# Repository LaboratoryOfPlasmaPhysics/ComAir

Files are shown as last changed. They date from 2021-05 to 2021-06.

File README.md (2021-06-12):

# ComAir

A LoRa air quality sensor powered with an indoor solar pannel.

This PCB uses:
- as MCU: [STM32L412C8](https://www.st.com/en/microcontrollers-microprocessors/stm32l412c8.html)
- for LoRa communication: [RFM95](https://www.hoperf.com/modules/lora/RFM95.html)
- for energy harvesting: [SPV1050](https://www.st.com/en/power-management/spv1050.html)
- any 18650 lithium cell (could be recycled from old laptop battery)
- as solar pannel, one or two: [LL200-4.8-37](https://www.powerfilmsolar.com/products/electronic-component-solar-panels/indoor-light-series/ll200-48-37) 
- for CO2 sensing: [SCD41](https://www.sensirion.com/en/environmental-sensors/carbon-dioxide-sensors/carbon-dioxide-sensor-scd4x/)
- for temperature and humidity: either [SCD41](https://www.sensirion.com/en/environmental-sensors/carbon-dioxide-sensors/carbon-dioxide-sensor-scd4x/) or [SHTC3](https://www.sensirion.com/en/environmental-sensors/humidity-sensors/digital-humidity-sensor-shtc3-our-new-standard-for-consumer-electronics/)

**Warning** this project is still work in progress, PCB may still contain errors.

PCB V1.0 preview:
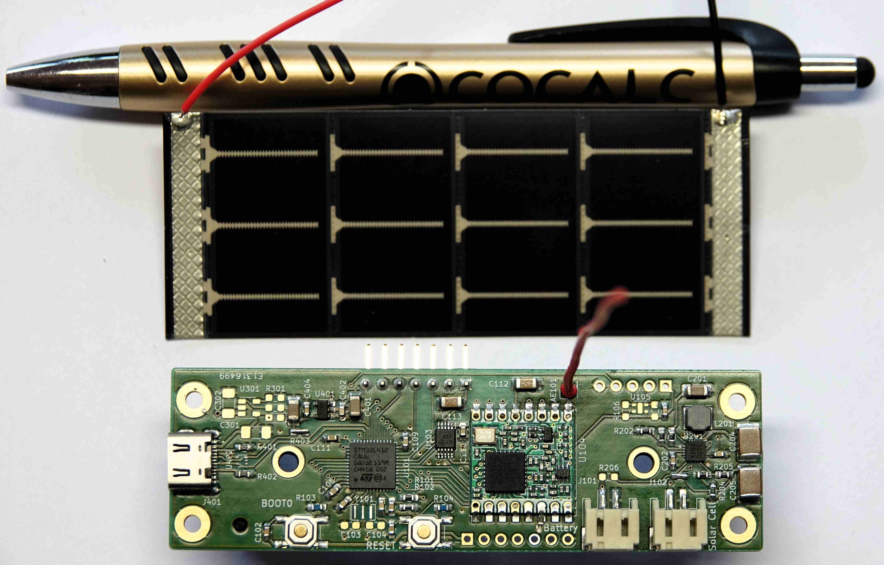
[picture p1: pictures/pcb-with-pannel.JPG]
PCB with solar pannel


## TODO

- [ ] Write some basic testing firmware
- [ ] Evaluate energy balance 
- [ ] Optimize energy usage

## License 
- CC-BY-SA

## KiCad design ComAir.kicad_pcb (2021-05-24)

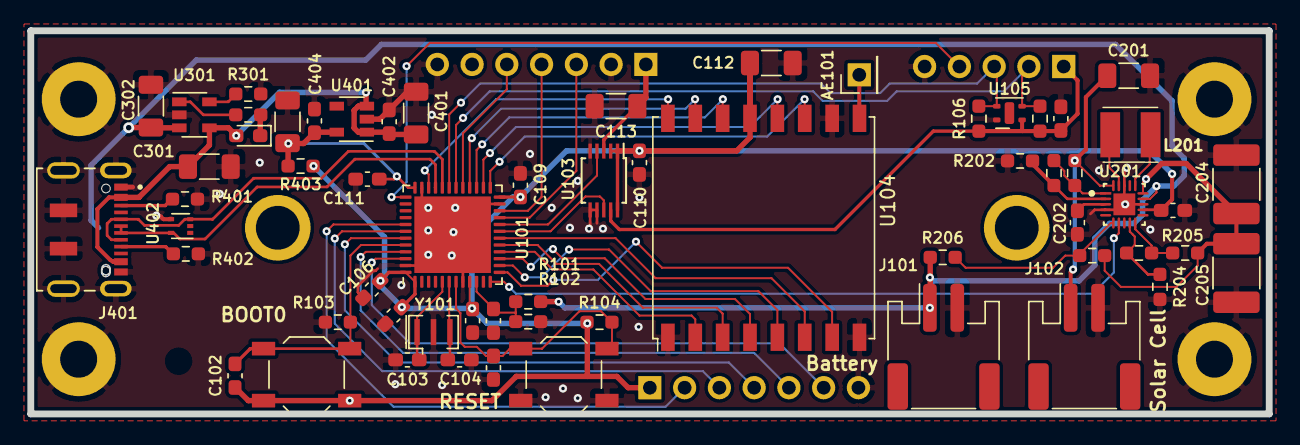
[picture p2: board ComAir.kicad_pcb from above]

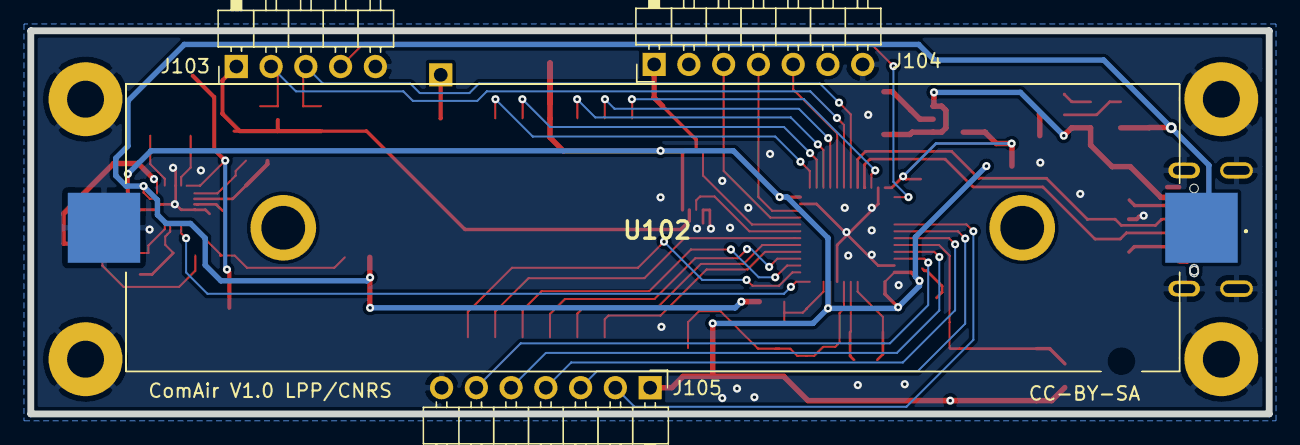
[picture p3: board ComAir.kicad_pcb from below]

Board: 2 copper layers, 90.5 x 28.0 mm, 69 parts (4 on the bottom side), 55 nets.

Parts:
AE101: Antenna; PinHeader_1x01_P2.54mm_Vertical
C101, C102, C105, C106, C107, C108, C109, C110, C111, C114, C202, C203, C402, C404: 100nF; C_0603_1608Metric_Pad1.08x0.95mm_HandSolder
C103, C104: 20pF; C_0603_1608Metric_Pad1.08x0.95mm_HandSolder
C112, C113: 10uF; C_1206_3216Metric_Pad1.33x1.80mm_HandSolder
C201: 1uF; C_1206_3216Metric_Pad1.33x1.80mm_HandSolder
C204, C205: 47uF; C_1812_4532Metric_Pad1.57x3.40mm_HandSolder
C301, C302, C401, C403: 4.7uF; C_1206_3216Metric_Pad1.33x1.80mm_HandSolder
D301: LED; LED_0603_1608Metric_Pad1.05x0.95mm_HandSolder
H101, H102, H103, H104: MountingHole_Pad; MountingHole_2.7mm_M2.5_Pad
J101, J102: Conn_01x02; JST_PH_S2B-PH-SM4-TB_1x02-1MP_P2.00mm_Horizontal
J103: Conn_01x05; PinHeader_1x05_P2.54mm_Horizontal
J104, J105: Conn_01x07; PinHeader_1x07_P2.54mm_Horizontal
J401: DX07S016JA1R1500; JAE_DX07S016JA1R1500
L201: L; LQH44PH100MPRL
R101: 1M; R_0603_1608Metric_Pad0.98x0.95mm_HandSolder
R102: 2M; R_0603_1608Metric_Pad0.98x0.95mm_HandSolder
R103, R104: 10k; R_0603_1608Metric_Pad0.98x0.95mm_HandSolder
R105, R106: 4k7; R_0603_1608Metric_Pad0.98x0.95mm_HandSolder
R201, R202, R203, R204, R205, R206, R207, R208: R; R_0603_1608Metric_Pad0.98x0.95mm_HandSolder
R301: 2k; R_0603_1608Metric_Pad0.98x0.95mm_HandSolder
R302: 470; R_0603_1608Metric_Pad0.98x0.95mm_HandSolder
R401, R402: 5.1k; R_0603_1608Metric_Pad0.98x0.95mm_HandSolder
R403: 0; R_0603_1608Metric_Pad0.98x0.95mm_HandSolder
SW101, SW102: SW_Push; SW_SPST_TL3342
U101: STM32L431CBUx; QFN-48-1EP_7x7mm_P0.5mm_EP5.6x5.6mm
U102: 12BHC186P1-GR; 12BHC186P1GR
U103: TS3A24159DGSR; TSSOP-10_3x3mm_P0.5mm
U104: RFM95W-868S2; HOPERF_RFM9XW_SMD
U105: SHTC3; Sensirion_DFN-4-1EP_2x2mm_P1mm_EP0.7x1.6mm
U201: SPV1050TTR; STMicroelectronics-SPV1050TTR-0
U301: MCP73831-2-OT; SOT-23-5
U401: NCP718xSN330; SOT-23-5
U402: TPD2E2U06; SOT-553
Y101: Crystal_GND2_Small; Resonator_SMD_muRata_CSTxExxV-3Pin_3.0x1.1mm

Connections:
/3V3: C102.1, C105.1, C106.1, C108.1, C109.1, C110.1, C112.1, C203.1, J105.1, R104.1, R403.2, SW101.1, U101.1, U101.9, U101.24, U101.48, U103.1, U103.2, U103.10, U104.13, U201.12
/3V3_SCD30: C113.1, J104.1, U103.3
/BOOT0: C102.2, R103.1, SW101.2, U101.44
/I2C1_SCL: J103.2, R105.2, U101.30, U105.2
/I2C1_SDA: J103.3, R106.2, U101.31, U105.3
/I2C2_SCL: J104.3, U101.21
/I2C2_SDA: J104.4, U101.22
/LORA_DIO0: U101.27, U104.14
/LORA_DIO1: U101.28, U104.15
/LORA_DIO2: U101.34, U104.16
/LORA_DIO3: U101.25, U104.11
/LORA_DIO4: U101.26, U104.12
/LORA_DIO5: U101.13, U104.7
/LORA_RESET: U101.18, U104.6
/LP_SENSORS_3V3: C114.1, J103.1, R105.1, R106.1, U103.9, U105.1
/LP_SENSORS_PW_EN: U101.19, U103.8
/OneWire: J103.4, U101.37
/PB5: J105.2, U101.41
/PB6: J105.3, U101.42
/PB7: J105.4, U101.43
/PB8: J105.5, U101.45
/PB9: J105.6, U101.46
/Power_Harvester/Store: C204.1, C205.1, R205.1, R207.1, U201.15
/SCD30_PW_EN: U101.20, U103.4
/SCD30_RDY: J104.5, U101.29
/SPI1_MISO: U101.16, U104.2
/SPI1_MOSI: U101.17, U104.3
/SPI1_NSS: U101.14, U104.5
/SPI1_SCK: U101.15, U104.4
/SolarCell: C201.1, J102.1, R201.1, U201.20
/USB_D+: J401.6, J401.7, U101.33, U402.5
/USB_D-: J401.5, J401.8, U101.32, U402.3
/USB_VBUS: C301.1, C401.1, C402.1, D301.2, J401.2, J401.11, U301.4, U401.1, U401.3
/VBAT_Sense: C101.1, R101.2, R102.1, U101.10
/VBat: C302.1, J101.1, R101.1, R206.1, U102.1, U201.14, U301.3
/VDD_USB: C111.1, C403.1, C404.1, R403.1, U101.36, U401.5
/~BATT_CHRG: U101.12, U201.7
/~RESET: C107.1, R104.2, SW102.1, U101.7
GND: C101.2, C103.2, C104.2, C105.2, C106.2, C107.2, C108.2, C109.2, C110.2, C111.2, C112.2, C113.2, C114.2, C201.2, C202.2, C203.2, C204.2, C205.2, C301.2, C302.2, C401.2, C402.2, C403.2, C404.2, H101.1, H102.1, H103.1, H104.1, J101.2, J102.2, J103.5, J104.2, J104.7, J105.7, J401.1, J401.12, J401.S1, J401.S2, J401.S3, J401.S4, J401.S5, J401.S6, R102.2, R103.2, R202.1, R204.1, R301.2, R401.1, R402.1, SW102.2, U101.8, U101.23, U101.35, U101.47, U101.49, U102.2, U103.5, U103.6, U103.7, U104.1, U104.8, U104.10, U105.4, U201.4, U201.13, U201.18, U201.21, U301.2, U401.2, U402.4, Y101.2
unnamed: AE101.1, U104.9
unnamed: C103.1, U101.5, Y101.1
unnamed: C104.1, U101.6, Y101.3
unnamed: C202.1, U201.3
unnamed: D301.1, R302.1
unnamed: J401.3, R401.2
unnamed: J401.9, R402.2
unnamed: L201.1, U201.19
unnamed: L201.2, U201.16
unnamed: R201.2, R203.1, U201.1
unnamed: R202.2, R203.2, U201.2
unnamed: R204.2, R208.1, U201.9
unnamed: R205.2, R208.2, U201.10
unnamed: R206.2, R207.2, U201.6
unnamed: R301.1, U301.5
unnamed: R302.2, U301.1

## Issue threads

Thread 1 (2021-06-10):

USB DFU bootloader blocked because of RFM95 module (DIO5)

jeandet, 2021-06-10:
There is no pull down resistor on RFM95 reset pin and DIO5 by default is clkout, this prevent the MCU to enter DFU mode generating a lot of:
```
[268721.923613] usb 5-3-port4: attempt power cycle
[268722.526763] usb 5-3.4: new full-speed USB device number 111 using xhci_hcd
[268722.526854] usb 5-3.4: Device not responding to setup address.
[268722.731529] usb 5-3.4: Device not responding to setup address.
[268722.938996] usb 5-3.4: device not accepting address 111, error -71
[268723.015776] usb 5-3.4: new full-speed USB device number 112 using xhci_hcd
[268723.015881] usb 5-3.4: Device not responding to setup address.
[268723.219173] usb 5-3.4: Device not responding to setup address.
[268723.426869] usb 5-3.4: device not accepting address 112, error -71
[268723.427205] usb 5-3-port4: unable to enumerate USB device
```
The simplest solution is to disconnect this pin which should be useless.

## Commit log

2021-05-12 initial release
    [ComAir.kicad_pcb, ComAir.sch, Power.sch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]
2021-05-24 PCB ready for first prototype production
    [ComAir.kicad_pcb]
